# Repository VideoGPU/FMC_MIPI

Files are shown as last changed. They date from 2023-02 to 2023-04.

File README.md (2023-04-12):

# FMC_MIPI
FMC card to allow interfacing Xilinx FPGA boards with Jetson TX2 or TX1 via CSI-2 camera interface.
Made with KiCad.
Tested and works fine with KC705

HS and LP lanes come as a separate lines from FPGA.Switching between HS and LP modes is done using a high-speed switch 
TS3DDR3812.

## Some pictures:
Terminal output:

Example output:
The vertical line position in magenta strip indicates a frame number


The whole setup:


Interconnector board:




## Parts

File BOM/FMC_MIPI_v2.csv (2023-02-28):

Comment | Designator | Footprint | LCSC
4.7uF | C4,C29,C30,C31 | Capacitors_SMD:C_0805 | C1779
1uF | C7,C8,C25,C26,C27,C28 | Capacitors_SMD:C_0805 | C28323
0.1uF | C1,C2,C3,C5,C6,C9,C10,C11,C12,C13,C14,C15,C16,C17,C18,C19,C20,C21,C22,C23,C24,C32,C33,C34,C35,C36,C37,C38,C39,C40,C41 | Capacitors_SMD:C_0402 | C1525
UCLAMP0501H.TCT | D1,D2,D3,D4 | SODFL1608X70N | C117557
SN74AVC4T245PWR | IC1 | SOP65P640X120-16N | C81461
AT24MAC402-MAHM-T | IC2 | SON50P300X200X60-9N | C2061210
TCA9406DCUR | IC3,IC4,IC5 | SOP50P310X90-8N | C840107
SN74AVC1T45DCKT | IC6,IC7 | SOT65P210X110-6N | C2677669
ASP-134488-01 | J1 | FMC_MIPI_v2_sym:ASP-134488-01_VER2 | C2762238
QTH-060-01-L-D-A | J2 | FMC_MIPI_v2_sym:QTH-060-01-X-D-A-QTH-060-01-X-D-A | C3640977
Conn_01x08_Female | J3 | Connector_PinHeader_2.54mm:PinHeader_2x04_P2.54mm_Vertical | DnP
Jumper_3_Bridged12 | JP1 | Pin_Headers:Pin_Header_Straight_1x03_Pitch2.54mm | DnP
Jumper | JP2,JP3 | Pin_Headers:Pin_Header_Straight_1x02_Pitch2.54mm | DnP
0 | R1,R6,R7,R8,R12,R13,R14,R15,R16,R17,R18,R19,R20,R21,R22,R23,R24,R25,R26,R27,R28,R36,R37,R38,R75 | Resistors_SMD:R_0805 | C17477
2.2k | R29,R31,R32,R34 | Resistors_SMD:R_0805 | C17520
220 | R39,R40,R45,R46,R51,R52,R57,R58,R63,R64,R69,R70 | Resistors_SMD:R_0603 | C107696
47 | R41,R42,R47,R48,R53,R54,R59,R60,R65,R66,R71,R72 | Resistors_SMD:R_0603 | C114623
9.1 | R43,R44,R49,R50,R55,R56,R61,R62,R67,R68,R73,R74 | Resistors_SMD:R_0603 | C103890
4.7k | R2,R3,R4,R5,R9,R10,R11,R30,R33,R35 | Resistors_SMD:R_0805 | C17673
GND | TP1,TP2 | TestPoint:TestPoint_Keystone_5010-5014_Multipurpose | DnP
LP5907MFX-1.8 | U1 | Package_TO_SOT_SMD:SOT-23-5 | C92498
SN74AVC2T45DCUR | U2 | FMC_MIPI_v2_sym:SN74AVC2T45DCUR | C140318
SN74AVCH16T245GR | U3,U8 | SOP50P810X120-48N | C181413
TLV75525PDBV | U4 | TO_SOT_Packages_SMD:SOT-23-5 | C2867155
TS3DDR3812_RUA_42 | U5,U6 | FMC_MIPI_v2_sym:TS3DDR3812RUAR | C181266
LP5907MFX-1.2 | U7 | Package_TO_SOT_SMD:SOT-23-5 | C73478

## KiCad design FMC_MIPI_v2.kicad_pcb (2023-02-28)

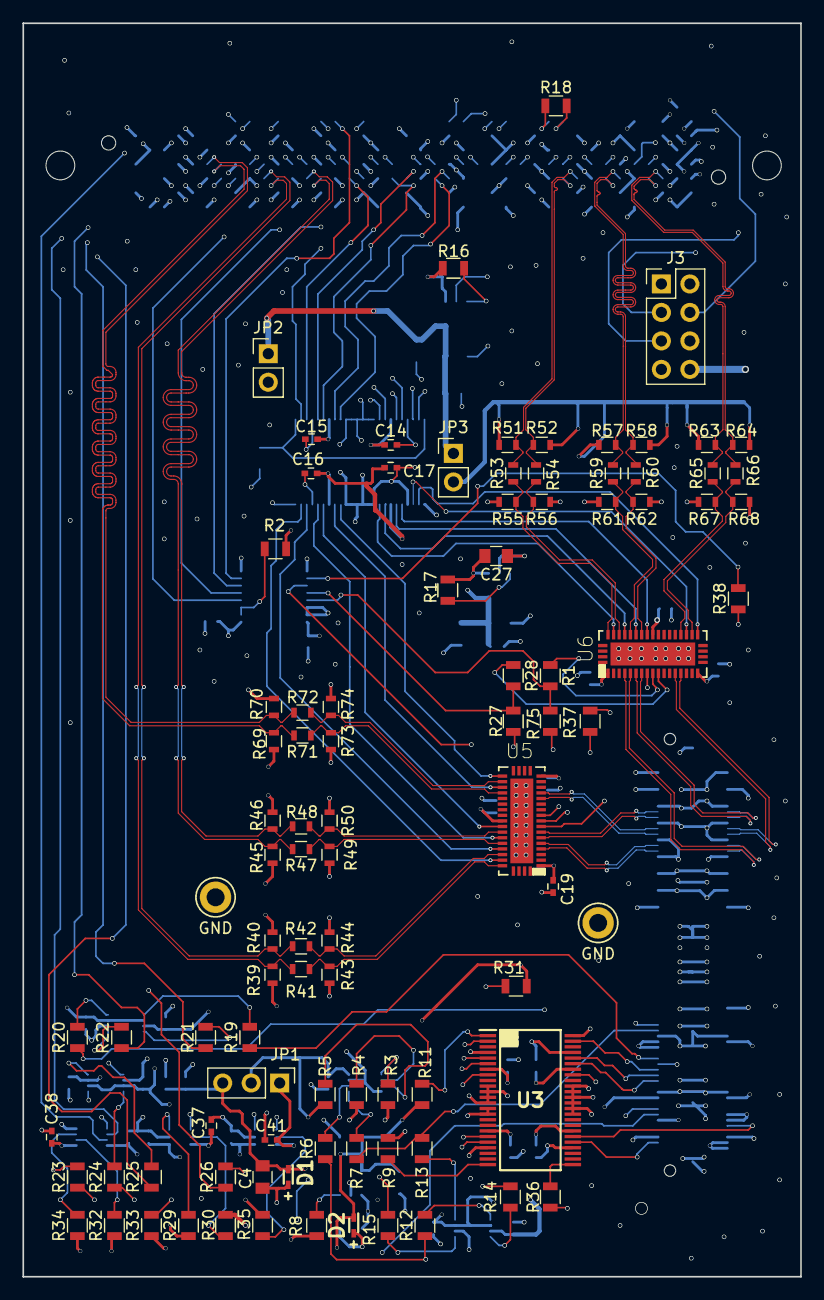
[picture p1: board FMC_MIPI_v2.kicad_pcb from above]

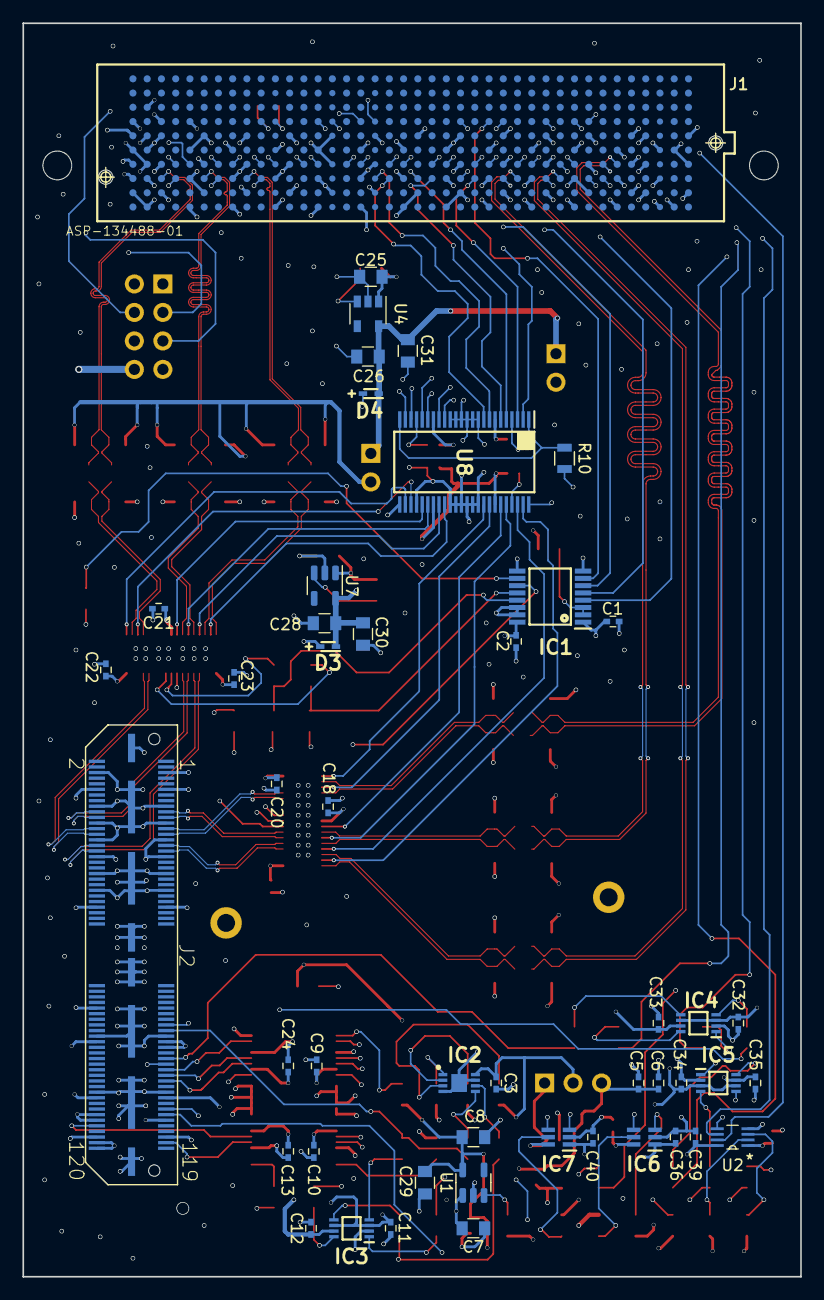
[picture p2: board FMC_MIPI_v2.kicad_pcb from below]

Board: 6 copper layers, 69.3 x 111.8 mm, 143 parts (48 on the bottom side), 156 nets.

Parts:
C1, C2, C3, C5, C6, C9, C10, C11, C12, C13, C14, C15, C16, C17, C18, C19, C20, C21, C22, C23, C24, C32, C33, C34, C35, C36, C37, C38, C39, C40, C41: 0.1uF; C_0402
C4, C29, C30, C31: 4.7uF; C_0805
C7, C8, C25, C26, C27, C28: 1uF; C_0805
D1, D2, D3, D4: UCLAMP0501H.TCT; SODFL1608X70N
IC1: SN74AVC4T245PWR; SOP65P640X120-16N
IC2: AT24MAC402-MAHM-T; SON50P300X200X60-9N
IC3, IC4, IC5: TCA9406DCUR; SOP50P310X90-8N
IC6, IC7: SN74AVC1T45DCKT; SOT65P210X110-6N
J1: ASP-134488-01; ASP-134488-01_VER2
J2: QTH-060-01-L-D-A; QTH-060-01-X-D-A-QTH-060-01-X-D-A
J3: Conn_01x08_Female; PinHeader_2x04_P2.54mm_Vertical
JP1: Jumper_3_Bridged12; Pin_Header_Straight_1x03_Pitch2.54mm
JP2, JP3: Jumper; Pin_Header_Straight_1x02_Pitch2.54mm
R1, R6, R7, R8, R12, R13, R14, R15, R16, R17, R18, R19, R20, R21, R22, R23, R24, R25, R26, R27, R28, R36, R37, R38, R75: 0; R_0805
R2, R3, R4, R5, R9, R10, R11, R30, R33, R35: 4.7k; R_0805
R29, R31, R32, R34: 2.2k; R_0805
R39, R40, R45, R46, R51, R52, R57, R58, R63, R64, R69, R70: 220; R_0603
R41, R42, R47, R48, R53, R54, R59, R60, R65, R66, R71, R72: 47; R_0603
R43, R44, R49, R50, R55, R56, R61, R62, R67, R68, R73, R74: 9.1; R_0603
TP1, TP2: GND; TestPoint_Keystone_5010-5014_Multipurpose
U1: LP5907MFX-1.8; SOT-23-5
U2: SN74AVC2T45DCUR
U3, U8: SN74AVCH16T245GR; SOP50P810X120-48N
U4: TLV75525PDBV; SOT-23-5
U5, U6: TS3DDR3812_RUA_42; TS3DDR3812RUAR
U7: LP5907MFX-1.2; SOT-23-5

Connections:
/FMC_Connector/DBG_IO_1: J1.G34 (LA31_N), J3.1
/FMC_Connector/DBG_IO_2: J1.G37 (LA33_N), J3.2
/FMC_Connector/DBG_IO_3: J1.G36 (LA33_P), J3.3
/FMC_Connector/DBG_IO_4: J1.G31 (LA29_N), J3.4
/FMC_Connector/DBG_IO_5: J1.D24 (LA23_N), J3.5
/FMC_Connector/DBG_IO_6: J1.D23 (LA23_P), J3.6
/FMC_Connector/TDI: J1.D30 (TDI), R18.1
/FMC_Connector/TDO: J1.D31 (TDO), R18.2
/Jetson_connector/EEPROM_A0: IC2.1 (A0), R3.1
/Jetson_connector/EEPROM_A1: IC2.2 (A1), R4.1
/Jetson_connector/EEPROM_A2: IC2.3 (A2), R5.1
/Jetson_connector/EEPROM_SCL: IC2.6 (SCL), R6.1
/Jetson_connector/EEPROM_SDA: IC2.5 (SDA), R7.1
/Jetson_connector/JT_VDD_1V2: J2.101 (DVDD_CAM_IO_1V2), R29.1
/Jetson_connector/JT_VDD_2V8: J2.81 (AVDD_CAM), J2.82 (AVDD_CAM), J2.83 (AVDD_CAM), R32.1
/Jetson_connector/JT_VDD_3V3: J2.108 (VDD_3V3_SLP1), J2.110 (VDD_3V3_SLP2), R34.1
/Jetson_connector/JT_VDD_5V: J2.109 (VDD_5V), J2.118 (VDD_5V), J2.120 (VDD_5V)
/Jetson_connector/VCC_1V8_EEPROM: C3.1, IC2.8 (VCC), JP1.2 (C), R5.2
/LVDS_to_Jetson_lines/CSI_LP_C_CLK_N: U5.24 (C8), U8.41 (1A5)
/LVDS_to_Jetson_lines/CSI_LP_C_CLK_P: U5.22 (C9), U8.40 (1A6)
/LVDS_to_Jetson_lines/CSI_LP_C_D0_N: U5.33 (C4), U8.44 (1A3)
/LVDS_to_Jetson_lines/CSI_LP_C_D0_P: U5.31 (C5), U8.43 (1A4)
/LVDS_to_Jetson_lines/CSI_LP_C_D1_N: U5.37 (C2), U8.47 (1A1)
/LVDS_to_Jetson_lines/CSI_LP_C_D1_P: U5.35 (C3), U8.46 (1A2)
/LVDS_to_Jetson_lines/CSI_LP_D_CLK_N: U6.24 (C8), U8.27 (2A7)
/LVDS_to_Jetson_lines/CSI_LP_D_CLK_P: U6.22 (C9), U8.26 (2A8)
/LVDS_to_Jetson_lines/CSI_LP_D_D0_N: U6.33 (C4), U8.30 (2A5)
/LVDS_to_Jetson_lines/CSI_LP_D_D0_P: U6.31 (C5), U8.29 (2A6)
/LVDS_to_Jetson_lines/CSI_LP_D_D1_N: U6.37 (C2), U8.33 (2A3)
/LVDS_to_Jetson_lines/CSI_LP_D_D1_P: U6.35 (C3), U8.32 (2A4)
/LVDS_to_Jetson_lines/DIR_IC1: IC1.2 (1DIR), IC1.3 (2DIR), R2.2
/LVDS_to_Jetson_lines/DIR_U8: R10.1, U8.1 (1DIR), U8.24 (2DIR)
/LVDS_to_Jetson_lines/EN_MIPI_OUT_CSI_C: IC1.11 (2B1), R37.2
/LVDS_to_Jetson_lines/EN_MIPI_OUT_CSI_D: IC1.10 (2B2), R38.2
/LVDS_to_Jetson_lines/EN_U5: R37.1, U5.8 (EN)
/LVDS_to_Jetson_lines/EN_U6: R38.1, U6.8 (EN)
/LVDS_to_Jetson_lines/HS_CSI_C_CLK_N: R71.1, R73.2, U5.25 (B8)
/LVDS_to_Jetson_lines/HS_CSI_C_CLK_P: R72.1, R74.1, U5.23 (B9)
/LVDS_to_Jetson_lines/HS_CSI_C_D0_N: R47.1, R49.2, U5.34 (B4)
/LVDS_to_Jetson_lines/HS_CSI_C_D0_P: R48.1, R50.1, U5.32 (B5)
/LVDS_to_Jetson_lines/HS_CSI_C_D1_N: R41.1, R43.2, U5.38 (B2)
/LVDS_to_Jetson_lines/HS_CSI_C_D1_P: R42.1, R44.1, U5.36 (B3)
/LVDS_to_Jetson_lines/HS_CSI_D_CLK_N: R65.1, R67.2, U6.25 (B8)
/LVDS_to_Jetson_lines/HS_CSI_D_CLK_P: R66.1, R68.1, U6.23 (B9)
/LVDS_to_Jetson_lines/HS_CSI_D_D0_N: R59.1, R61.2, U6.34 (B4)
/LVDS_to_Jetson_lines/HS_CSI_D_D0_P: R60.1, R62.1, U6.32 (B5)
/LVDS_to_Jetson_lines/HS_CSI_D_D1_N: R53.1, R55.2, U6.38 (B2)
/LVDS_to_Jetson_lines/HS_CSI_D_D1_P: R54.1, R56.1, U6.36 (B3)
/LVDS_to_Jetson_lines/SWITCH1_U5: R75.1, U5.9 (SEL1)
/LVDS_to_Jetson_lines/SWITCH1_U6: R1.1, U6.9 (SEL1)
/LVDS_to_Jetson_lines/SWITCH2_U5: R27.1, U5.10 (SEL2)
/LVDS_to_Jetson_lines/SWITCH2_U6: R28.1, U6.10 (SEL2)
/LVDS_to_Jetson_lines/SWITCH_CLOCK_LANES_CSI_CD: IC1.12 (1B2), R27.2, R28.2
/LVDS_to_Jetson_lines/SWITCH_DATA_LANES_CSI_CD: IC1.13 (1B1), R1.2, R75.2
/LVDS_to_Jetson_lines/VOLT_2P5_CSI_C: JP2.2, R39.1, R40.2, R45.1, R46.2, R69.1, R70.2
/LVDS_to_Jetson_lines/VOLT_2P5_CSI_D: JP3.2, R51.1, R52.2, R57.1, R58.2, R63.1, R64.2
/Slow_signals_level_shifters/1DIR_U3: R11.1, U3.1 (1DIR)
/Slow_signals_level_shifters/2DIR_U3: R9.1, U3.24 (2DIR)
/Slow_signals_level_shifters/ENN_JETSON_GPIO: IC7.4 (B), R36.2
/VDD_VADJ: C1.2, C9.1, C10.1, C12.1, C14.1, C15.1, C33.1, C35.1, C37.2, C39.2, C40.2, IC1.1 (VCCA), IC3.7 (VCCB), IC4.7 (VCCB), IC5.7 (VCCB), IC6.6 (VCCB), IC7.1 (VCCA), J1.E39 (VADJ), J1.F40 (VADJ), J1.G39 (VADJ), J1.H40 (VADJ), R2.1, R35.1, U2.8 (VCCB), U3.7 (VCCB_1), U3.18 (VCCB_2), U8.7 (VCCB_1), U8.18 (VCCB_2)
/VOLT_1P2: C16.1, C17.1, C28.2, C30.2, C36.2, D3.1, IC6.1 (VCCA), R30.1, U7.5 (OUT), U8.31 (VCCA_1), U8.42 (VCCA_2)
/VOLT_1P8: C8.2, C11.1, C13.1, C24.1, C29.2, C32.1, C34.1, C41.2, D2.1, IC3.3 (VCCA), IC3.6 (OE), IC4.3 (VCCA), IC4.6 (OE), IC5.3 (VCCA), IC5.6 (OE), IC7.6 (VCCB), JP1.1 (A), R11.2, U1.5 (OUT), U3.31 (VCCA_1), U3.42 (VCCA_2)
/VOLT_2P5: C26.2, C31.2, D4.1, JP2.1, JP3.1, U4.5 (OUT)
/VOLT_3P3: C2.2, C7.2, C18.2, C19.2, C20.2, C21.2, C22.2, C23.2, C25.2, C27.2, C38.2, IC1.16 (VCCB), J1.C39 (3PV3), J1.D36 (3P3V), J1.D38 (3P3V), J1.D40 (3P3V), R8.1, R16.1, R17.1, R33.1, U1.1 (IN), U2.1 (VCCA), U4.1 (IN), U5.1 (VCC), U5.17 (VCC), U5.30 (VCC), U6.1 (VCC), U6.17 (VCC), U6.30 (VCC), U7.1 (IN)
CSI_C_CLK_N: J2.27 (CSI2_CLK–), U5.13 (A8)
CSI_C_CLK_P: J2.25 (CSI2_CLK+), U5.14 (A9)
CSI_C_D0_N: J2.21 (CSI2_D0–), U5.6 (A4)
CSI_C_D0_P: J2.19 (CSI2_D0+), U5.7 (A5)
CSI_C_D1_N: J2.33 (CSI2_D1–), U5.4 (A2)
CSI_C_D1_P: J2.31 (CSI2_D1+), U5.5 (A3)
CSI_D_CLK_N: J2.28 (CSI3_CLK–), U6.13 (A8)
CSI_D_CLK_P: J2.26 (CSI3_CLK+), U6.14 (A9)
CSI_D_D0_N: J2.22 (CSI3_D0–), U6.6 (A4)
CSI_D_D0_P: J2.20 (CSI3_D0+), U6.7 (A5)
CSI_D_D1_N: J2.34 (CSI3_D1–), U6.4 (A2)
CSI_D_D1_P: J2.32 (CSI3_D1+), U6.5 (A3)
Earth: C1.1, C2.1, C3.2, C4.1, C5.1, C6.1, C7.1, C8.1, C9.2, C10.2, C11.2, C12.2, C13.2, C14.2, C15.2, C16.2, C17.2, C18.1, C19.1, C20.1, C21.1, C22.1, C23.1, C24.2, C25.1, C26.1, C27.1, C28.1, C29.1, C30.1, C31.1, C32.2, C33.2, C34.2, C35.2, C36.1, C37.1, C38.1, C39.1, C40.1, C41.1, D1.2, D2.2, D3.2, D4.2, IC1.8 (GND), IC1.9 (GND), IC1.14 (2~OE), IC1.15 (1~OE), IC2.4 (GND), IC2.7 (WP), IC2.9 (EP), IC3.2 (GND), IC4.2 (GND), IC5.2 (GND), IC6.2 (GND), IC7.2 (GND), J1.E1 (GND), J1.E4 (GND), J1.E5 (GND), J1.E8 (GND), J1.E11 (GND), J1.E14 (GND), J1.E17 (GND), J1.E20 (GND), J1.E23 (GND), J1.E26 (GND), J1.E29 (GND), J1.E32 (GND), J1.E35 (GND), J1.E38 (GND), J1.E40 (GND), J1.F2 (GND), J1.F3 (GND), J1.F6 (GND), J1.F9 (GND), J1.F12 (GND), J1.F15 (GND), J1.F18 (GND), J1.F21 (GND), J1.F24 (GND), J1.F27 (GND), J1.F30 (GND), J1.F33 (GND), J1.F36 (GND), J1.F39 (GND), J1.G1 (GND), J1.G4 (GND), J1.G5 (GND), J1.G8 (GND), J1.G11 (GND), J1.G14 (GND), J1.G17 (GND), J1.G23 (GND), J1.G26 (GND), J1.G29 (GND), J1.G32 (GND), J1.G35 (GND), J1.G38 (GND), J1.G40 (GND), J1.H3 (GND), J1.H6 (GND), J1.H9 (GND), J1.H12 (GND), J1.H15 (GND), J1.H18 (GND), J1.H21 (GND), J1.H24 (GND), J1.H27 (GND), J1.H30 (GND), J1.H33 (GND), J1.H36 (GND), J1.H39 (GND), J1.J1 (GND), J1.J4 (GND), J1.J5 (GND), J1.J8 (GND), J1.J11 (GND), J1.J14 (GND), J1.J17 (GND), J1.J20 (GND), J1.J23 (GND), J1.J26 (GND), J1.J29 (GND), J1.J32 (GND), J1.J35 (GND), J1.J38 (GND), J1.J40 (GND), J1.K2 (GND), J1.K3 (GND), J1.K6 (GND), J1.K9 (GND), J1.K12 (GND), J1.K15 (GND), J1.K18 (GND), J1.K21 (GND), J1.K24 (GND), J1.K27 (GND), J1.K30 (GND), J1.K33 (GND), J1.K36 (GND), J1.K39 (GND), J2.5 (GND), J2.6 (GND), J2.11 (GND), J2.12 (GND), J2.17 (GND), J2.18 (GND), J2.23 (GND), J2.24 (GND), J2.29 (GND), J2.30 (GND), J2.35 (GND), J2.36 (GND), J2.41 (GND), J2.42 (GND), J2.47 (GND), J2.48 (GND), J2.53 (GND), J2.54 (GND), J2.70 (GND), J2.79 (GND), J2.80 (GND), J2.99 (GND), J2.100 (GND), J2.115 (GND), J2.116 (GND), J2.G1, J2.G2, J2.G3, J2.G4, J2.G5, J2.G6, J2.G7, J2.G8, J3.7, J3.8, R3.2, R4.2, R9.2, R10.2, R43.1, R44.2, R49.1, R50.2, R55.1, R56.2, R61.1, R62.2, R67.1, R68.2, R73.1, R74.2, TP1.1, TP2.1, U1.2 (GND), U2.4 (GND), U3.4 (GND_1), U3.10 (GND_2), U3.11 (1B7), U3.12 (1B8), U3.13 (2B1), U3.14 (2B2), U3.15 (GND_3), U3.21 (GND_4), U3.28 (GND_5), U3.34 (GND_6), U3.35 (2A2), U3.36 (2A1), U3.37 (1A8), U3.38 (1A7), U3.39 (GND_7), U3.45 (GND_8), U3.48 (1~OE), U4.2 (GND), U5.43 (EPAD), U6.43 (EPAD), U7.2 (GND), U8.4 (GND_1), U8.10 (GND_2), U8.11 (1B7), U8.12 (1B8), U8.13 (2B1), U8.14 (2B2), U8.15 (GND_3), U8.21 (GND_4), U8.25 (2~OE), U8.28 (GND_5), U8.34 (GND_6), U8.35 (2A2), U8.36 (2A1), U8.37 (1A8), U8.38 (1A7), U8.39 (GND_7), U8.45 (GND_8), U8.48 (1~OE)
FMC_1P2V_MONITOR: IC6.4 (B), J1.H8 (LA02_N)
FMC_1P8V_MONITOR: J1.G27 (LA25_P), U3.8 (1B5)
FMC_2P8V_MONITOR: J1.D8 (LA01_P_CC), U2.7 (B1)
FMC_3P3V_MONITOR: J1.D9 (LA01_N_CC), U2.6 (B2)
FMC_CAM0_MCLK: J1.G33 (LA31_P), U3.2 (1B1)
FMC_CAM0_PWR: J1.G30 (LA29_P), U3.5 (1B3)
FMC_CAM0_RST: J1.G28 (LA25_N), U3.6 (1B4)
FMC_CSI_LP_C_CLK_N: J1.H23 (LA19_N), U8.8 (1B5)
FMC_CSI_LP_C_CLK_P: J1.H22 (LA19_P), U8.9 (1B6)
FMC_CSI_LP_C_D0_N: J1.H20 (LA15_N), U8.5 (1B3)
FMC_CSI_LP_C_D0_P: J1.H19 (LA15_P), U8.6 (1B4)
FMC_CSI_LP_C_D1_N: J1.H17 (LA11_N), U8.2 (1B1)
FMC_CSI_LP_C_D1_P: J1.H16 (LA11_P), U8.3 (1B2)
FMC_CSI_LP_D_CLK_N: J1.G22 (LA20_N), U8.22 (2B7)
FMC_CSI_LP_D_CLK_P: J1.G21 (LA20_P), U8.23 (2B8)
FMC_CSI_LP_D_D0_N: J1.G19 (LA16_N), U8.19 (2B5)
FMC_CSI_LP_D_D0_P: J1.G18 (LA16_P), U8.20 (2B6)
FMC_CSI_LP_D_D1_N: J1.G16 (LA12_N), U8.16 (2B3)
FMC_CSI_LP_D_D1_P: J1.G15 (LA12_P), U8.17 (2B4)
FMC_ENN_JT_GPIO_INPUT: IC7.3 (A), J1.D17 (LA13_P)
FMC_EN_MIPI_OUT_CLOCK_VADJ: IC1.7 (2A2), J1.D15 (LA09_N)
FMC_EN_MIPI_OUT_DATA_VADJ: IC1.6 (2A1), J1.D14 (LA09_P)
FMC_GPIO9_OUT: J1.D27 (LA26_N), U3.19 (2B5)
FMC_GPIO17_OUT: J1.D26 (LA26_P), U3.20 (2B6)
FMC_HS_CSI_C_CLK_N: J1.G7 (LA00_N_CC), R69.2, R71.2
FMC_HS_CSI_C_CLK_P: J1.G6 (LA00_P_CC), R70.1, R72.2
FMC_HS_CSI_C_D0_N: J1.H14 (LA07_N), R45.2, R47.2
FMC_HS_CSI_C_D0_P: J1.H13 (LA07_P), R46.1, R48.2
FMC_HS_CSI_C_D1_N: J1.H11 (LA04_N), R39.2, R41.2
FMC_HS_CSI_C_D1_P: J1.H10 (LA04_P), R40.1, R42.2
FMC_HS_CSI_D_CLK_N: J1.H38 (LA32_N), R63.2, R65.2
FMC_HS_CSI_D_CLK_P: J1.H37 (LA32_P), R64.1, R66.2
FMC_HS_CSI_D_D0_N: J1.H35 (LA30_N), R57.2, R59.2
FMC_HS_CSI_D_D0_P: J1.H34 (LA30_P), R58.1, R60.2
FMC_HS_CSI_D_D1_N: J1.H32 (LA28_N), R51.2, R53.2
FMC_HS_CSI_D_D1_P: J1.H31 (LA28_P), R52.1, R54.2
FMC_I2C2_CAM_CLK: J1.G9 (LA03_P), R21.2
FMC_I2C2_CAM_DAT: J1.D11 (LA05_P), R22.2
FMC_I2C3_CAM_CLK: J1.H7 (LA02_P), R25.2
FMC_I2C3_CAM_DAT: J1.G10 (LA03_N), R26.2
FMC_I2C_CAM_CLK: J1.G25 (LA22_N), R14.2
FMC_I2C_CAM_DAT: J1.G24 (LA22_P), R15.2
FMC_SWITCH_CLOCK_LANES_VADJ: IC1.5 (1A2), J1.G13 (LA08_N)
FMC_SWITCH_DATA_LANES_VADJ: IC1.4 (1A1), J1.G12 (LA08_P)
JT_1p8V_CAM0_MCLK: J2.91 (CAM0_MCLK), U3.47 (1A1)
JT_1p8V_CAM0_PWR: J2.93 (GPIO0_CAM0_PWR), U3.44 (1A3)
JT_1p8V_CAM0_RST: J2.95 (GPIO2_CAM0_RST), U3.43 (1A4)
JT_1p8V_GPIO9_IN: J2.112, U3.30 (2A5)
JT_1p8V_GPIO17_IN: J2.117 (CAM_INTR), U3.29 (2A6)
JT_1p8V_I2C2_CAM_CLK: J2.87 (CAM_I2C2_SCL), R19.1
JT_1p8V_I2C2_CAM_DAT: J2.89 (CAM_I2C2_SDA), R20.1
JT_1p8V_I2C3_CAM_CLK: J2.105 (I2C_GP0_CLK_1V8), R23.1
JT_1p8V_I2C3_CAM_DAT: J2.107 (I2C_GP0_DAT_1V8), R24.1
JT_1p8V_I2C_CAM_CLK: J2.75 (I2C_CAM_CLK), R6.2, R12.1
JT_1p8V_I2C_CAM_DAT: J2.77 (I2C_CAM_DAT), R7.2, R13.1
JT_VDD_1V8: C4.2, C5.2, C6.2, D1.1, J2.102 (DVDD_CAM_IO_1V8), JP1.3 (B), R31.2
unnamed: IC3.1 (SDA_B), R15.1
unnamed: IC3.4 (SDA_A), R13.2
unnamed: IC3.5 (SCL_A), R12.2
unnamed: IC3.8 (SCL_B), R14.1
unnamed: IC4.1 (SDA_B), R22.1
unnamed: IC4.4 (SDA_A), R20.2
unnamed: IC4.5 (SCL_A), R19.2
unnamed: IC4.8 (SCL_B), R21.1
unnamed: IC5.1 (SDA_B), R26.1
unnamed: IC5.4 (SDA_A), R24.2
unnamed: IC5.5 (SCL_A), R23.2
unnamed: IC5.8 (SCL_B), R25.1
unnamed: IC6.3 (A), R29.2
unnamed: IC6.5 (DIR), R30.2
unnamed: IC7.5 (DIR), R35.2
unnamed: R8.2, U1.3 (EN)
unnamed: R16.2, U4.3 (EN)
unnamed: R17.2, U7.3 (EN)
unnamed: R31.1, U3.41 (1A5)
unnamed: R32.2, U2.2 (A1)
unnamed: R33.2, U2.5 (DIR)
unnamed: R34.2, U2.3 (A2)
unnamed: R36.1, U3.25 (2~OE)

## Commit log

2017-08-01 Initial commit of v1 prototype
    [ADV7619_Power.sch, ADV_HDMI_Input.sch, BOM_Vorlage_2003_ENG_filled_MichaelLevit.xls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]
2021-09-13 baseline for version 2
    [ADV7619_Power.sch, ADV_HDMI_Input.sch, BOM_Vorlage_2003_ENG.xls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]
2021-09-13 starting from 0
    [ADV7619_Power.sch, ADV_HDMI_Input.sch, BOM_Vorlage_2003_ENG.xls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]
2021-09-16 re-organizing folder structure
    [FMC_MIPI_v2.kicad_pcb, FMC_MIPI_v2.sch]
2021-09-16 adding footprint libraries
    [FMC_MIPI_v2.sch]
2021-11-13 adding lvds to slvs
    [FMC_Connector.sch, FMC_MIPI_v2.sch, Jetson_connector.sch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]
2021-11-26 just commit
    [FMC_Connector.sch, FMC_MIPI_v2.sch, Jetson_connector.sch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]
2021-11-26 just commit2
    [FMC_Connector.sch, FMC_MIPI_v2.kicad_pcb, FMC_MIPI_v2.sch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]
2021-12-05 Good, before replacing the swithches to TI ones
    [FMC_Connector.sch, FMC_MIPI_v2.kicad_pcb, FMC_MIPI_v2.sch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]
2021-12-11 good, added re-driver
    [FMC_Connector.sch, FMC_MIPI_v2.kicad_pcb, FMC_MIPI_v2.sch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]
2021-12-11 good, before reducing
    [FMC_Connector.sch, FMC_MIPI_v2.kicad_pcb, FMC_MIPI_v2.sch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]
2022-10-20 before re-arranging
    [FMC_Connector.sch, FMC_MIPI_v2.kicad_pcb, FMC_MIPI_v2.sch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]
2022-10-23 rev 2022
    [FMC_Connector.sch, FMC_MIPI_v2.kicad_pcb, FMC_MIPI_v2.sch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]
2022-10-23 minor changes
    [FMC_MIPI_v2.kicad_pcb, LVDS_to_Jetson_lines.sch]
2022-10-23 good, before completely removing redriver part
    [LVDS_to_Jetson_lines.sch]
2022-10-25 fixed 3.3 volt level shifter
    [FMC_Connector.sch, FMC_MIPI_v2.kicad_pcb, FMC_MIPI_v2.sch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]
2022-10-28 added EEPROM
    [FMC_MIPI_v2.kicad_pcb, FMC_MIPI_v2.sch, Jetson_connector.sch]
2022-10-29 added more level shifters and power 1.8 Volt
    [FMC_MIPI_v2.kicad_pcb, FMC_MIPI_v2.sch, Jetson_connector.sch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]
2022-11-01 minor changes 4
    [FMC_Connector.sch, FMC_MIPI_v2.kicad_pcb, FMC_MIPI_v2.sch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]
2022-11-01 adding power supplies
    [FMC_Connector.sch, FMC_MIPI_v2.sch, Jetson_connector.sch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]
2022-11-01 adding more power supplies
    [FMC_Connector.sch, FMC_MIPI_v2.kicad_pcb, FMC_MIPI_v2.sch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]
2022-11-01 populating FMC connector
    [FMC_Connector.sch, FMC_MIPI_v2.kicad_pcb, Power.sch]
2022-11-01 cleanup 3D shapes
    [FMC_MIPI_v2.kicad_pcb, Jetson_connector.sch]
2022-11-03 Adding more LVDS lines
    [FMC_Connector.sch, FMC_MIPI_v2.kicad_pcb, FMC_MIPI_v2.sch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]
2022-11-05 added 4 bit level shifter VADJ to 3.3 volt
    [FMC_Connector.sch, FMC_MIPI_v2.kicad_pcb, FMC_MIPI_v2.sch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]
2022-11-05 removed unused components
    [FMC_Connector.sch, LVDS_2_SLVS.sch, LVDS_to_Jetson_lines.sch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]
2022-11-10 added enable line for slow signals
    [FMC_MIPI_v2.kicad_pcb, FMC_MIPI_v2.sch, Jetson_connector.sch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]
2022-11-11 Finished initial placement
    [FMC_MIPI_v2.kicad_pcb, LVDS_2_SLVS.sch, LVDS_to_Jetson_lines.sch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]
2022-11-11 minor changes in positions
    [FMC_MIPI_v2.kicad_pcb]
2022-11-12 placed nicely the components
    [FMC_MIPI_v2.kicad_pcb, LVDS_2_SLVS.sch]
2022-11-13 good, before FMC lines connect
    [FMC_MIPI_v2.kicad_pcb, FMC_MIPI_v2.sch, LVDS_2_SLVS.sch]
2022-11-13 Added dummy nets to FMC connector
    [FMC_Connector.sch, FMC_MIPI_v2.kicad_pcb, Jetson_connector.sch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]
2022-11-17 started routing
    [FMC_Connector.sch, FMC_MIPI_v2.kicad_pcb, LVDS_2_SLVS.sch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]
2022-11-22 before hi-speed routing
    [FMC_MIPI_v2.kicad_pcb, LVDS_2_SLVS.sch, LVDS_to_Jetson_lines.sch]
2022-11-22 converted to Kicad6
    [FMC_Connector.kicad_sch, FMC_MIPI_v2.kicad_sch, Jetson_connector.kicad_sch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]
2022-11-25 more routing
    [LVDS_to_Jetson_lines.kicad_sch]
2022-11-25 a little cleanup
    [FMC_Connector.kicad_sch, LVDS_to_Jetson_lines.kicad_sch]
2022-11-25 removed redundunt ground planes from
2022-11-26 good, before HS length tuning
    [FMC_MIPI_v2.kicad_pcb]
2022-12-03 DRC, ERC OK
    [FMC_Connector.kicad_sch, FMC_MIPI_v2.kicad_pcb, FMC_MIPI_v2.kicad_sch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]
2022-12-03 All warnings fixed
    [FMC_Connector.kicad_sch, FMC_MIPI_v2.kicad_pcb, FMC_MIPI_v2.kicad_sch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]
2022-12-03 Ready for BOM and Gerbers
    [FMC_MIPI_v2.kicad_pcb]
2022-12-05 Added BOM to gitignore
2022-12-06 JLCPCB BOM OK
    [FMC_Connector.kicad_sch, FMC_MIPI_v2.csv, FMC_MIPI_v2.kicad_pcb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]
2022-12-10 All DRC, ERC and BOM are good
    [FMC_Connector.kicad_sch, FMC_MIPI_v2.kicad_pcb, FMC_MIPI_v2.kicad_sch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]
2022-12-18 Added debug points
    [FMC_Connector.kicad_sch, FMC_MIPI_v2.kicad_pcb, FMC_MIPI_v2.kicad_sch]
2022-12-19 Added debug connector
    [FMC_Connector.kicad_sch, FMC_MIPI_v2.kicad_pcb]
2022-12-19 Generated BOM, before Gerbers generation
    [FMC_Connector.kicad_sch, FMC_MIPI_v2.csv, FMC_MIPI_v2.kicad_pcb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]
2022-12-19 generated gerbers and BOMs
    [BOM-FMC_MIPI_v2.csv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]
2026-10-17 KiCad symbol rescue for the FMC_MIPI_v2 schematic
    KiCad's symbol rescue rewrote FMC_MIPI_v2-rescue.lib with the symbols
    the schematic uses: ASP-134488-01 / QTH-060 connectors, AT24MAC402
    EEPROM, SN74AVC level shifters, TCA9406, TS3DDR3812 switch, UCLAMP0501H,
    LP5907 / TLV75525 regulators, C, jumper and earth. sym-lib-table now
    also lists the rescue library.
    Note: this KiCad also changed the FMC_MIPI_v2 entry (.kicad_sym) from
    type KiCad to Legacy. KiCad 6+ may fail to load it; check before
    merging into master.
